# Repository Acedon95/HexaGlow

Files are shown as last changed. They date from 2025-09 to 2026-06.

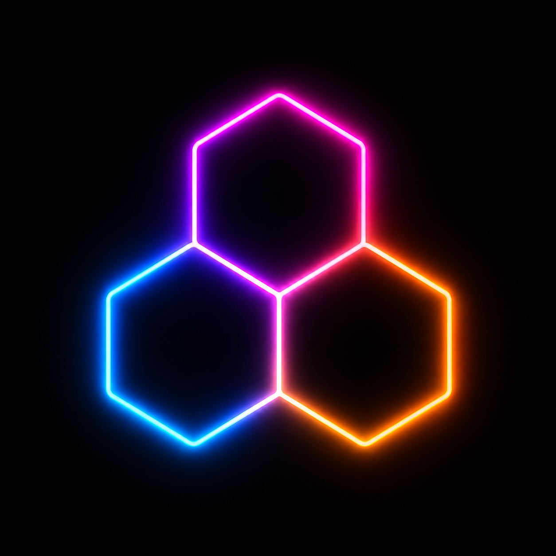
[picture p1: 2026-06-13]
app/hexaglow_app/assets/hexaglow_app_symbol.png

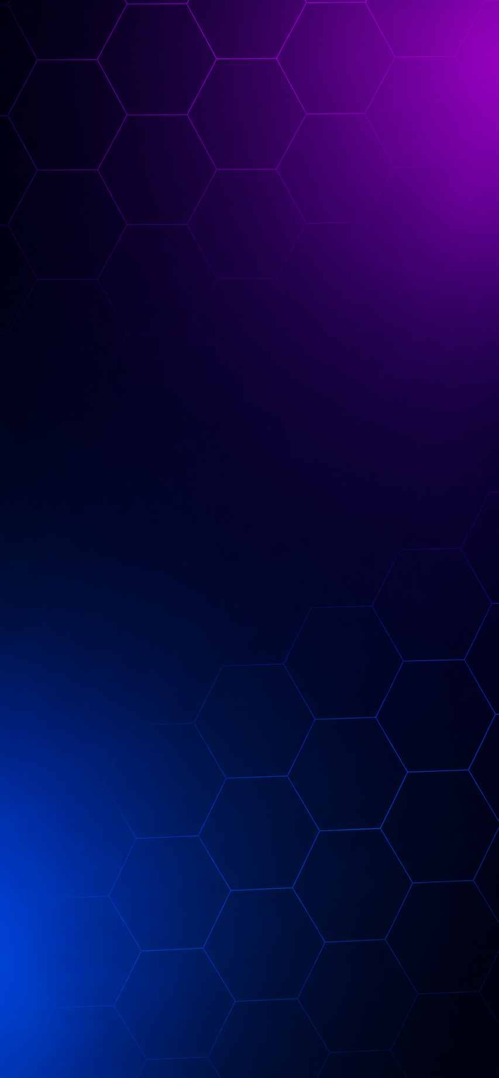
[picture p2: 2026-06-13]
app/hexaglow_app/assets/hexaglow_background_asset.png

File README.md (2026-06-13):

# HexaGlow

HexaGlow is a physical LED art piece made of **7 hexagons**, each ringed by
**18 WS2812B LEDs** (126 LEDs total), wired as one shared NeoPixel strip and
driven by an **ESP32**. The ESP32 connects to your WiFi and listens for
simple UDP text commands, which it translates into LED colors.

A companion **Flutter app** (Windows desktop + Android) provides a visual,
drag-to-arrange control surface: arrange the 7 hexagons to match your
physical layout, then tap edges/hexagons to pick colors, adjust brightness,
save/load presets, and clear the whole piece.

```
HexaGlow/
├── src/, include/, lib/, test/   ESP32 firmware (PlatformIO project)
├── data/                         SPIFFS filesystem image (WiFi credentials)
├── platformio.ini                Firmware build configuration
├── app/hexaglow_app/             Flutter app (Windows + Android)
└── hexagon_ring_outer100mm_*.stl 3D-printable hexagon ring (100mm, for 18 LEDs)
```

---

## 1. Firmware (ESP32)

The firmware is a [PlatformIO](https://platformio.org/) project rooted at
the repo root (`platformio.ini`, `src/`, `include/`).

### 1.1 Hardware setup

- **Board**: ESP32 dev kit (configured as `fm-devkit` in `platformio.ini`)
- **Data pin**: GPIO 4 (`LED_PIN` in [src/main.cpp](src/main.cpp))
- **LED count**: 126 (7 hexagons × 18 LEDs), type WS2812B (`NEO_GRB + NEO_KHZ800`)

NeoPixel best practices (see comments at the top of
[src/main.cpp](src/main.cpp)):
- Add a ~1000 µF capacitor across the strip's + and - rails.
- Keep the wire between the ESP32 and the first pixel short.
- Put a 300–500 Ω resistor on the data line.
- Always connect ground first when wiring live.
- A 3.3V → 5V logic-level converter on the data line is recommended.

### 1.2 WiFi configuration

The ESP32 connects to your WiFi as a client. Credentials are **not**
hardcoded — they're read at boot from a small config file stored in the
ESP32's SPIFFS filesystem.

1. Copy the example file and fill in your network details:
   ```
   data/.config.example  →  data/.config
   ```
   `data/.config` looks like:
   ```
   ssid:<your-ssid>
   password:<your-pw>
   ```
2. `data/.config` is **gitignored** (it contains real credentials) — make
   sure it exists locally before you upload the filesystem image.
3. Upload the filesystem image to the ESP32 (separately from the firmware):
   ```sh
   pio run --target uploadfs
   ```

You only need to redo step 3 when your WiFi credentials change.

### 1.3 Building and flashing the firmware

From the repo root (with the ESP32 connected via USB):

```sh
# Compile only (no hardware needed, useful to check for errors)
pio run

# Compile and flash to the connected ESP32
pio run --target upload

# Open a serial monitor at 115200 baud (boot logs, IP address, etc.)
pio device monitor
```

On boot, the ESP32:
1. Mounts SPIFFS and connects to WiFi using `data/.config`.
2. Prints its assigned IP address over serial (115200 baud) — **you need
   this IP address for the app's Settings screen**.
3. Plays a green "boot" animation, lighting up each hexagon in turn.
4. Starts listening for UDP commands on port **4210**.

> **Tip:** Your router may assign the ESP32 a different IP address after a
> power cycle unless you set up a DHCP reservation / static IP for it. If
> the app stops responding after a restart, check the serial monitor for the
> current IP and update it in the app's Settings screen.

### 1.4 UDP protocol reference

All commands are plain ASCII text, space-separated, sent as a single UDP
datagram to the ESP32's IP on port **4210**. This is the protocol the
Flutter app speaks; you can also test it manually with `nc -u <esp32-ip> 4210`.

| Command | Format | Description |
|---|---|---|
| Clear | `CLEAR` | Turns off all LEDs on all 7 hexagons. |
| Color all | `COLORALL r g b` | Sets every LED on the whole strip to one color. |
| Color hexagon | `COLORHEX hex_index r g b` | Sets every LED of one hexagon to one color. |
| Color edge | `COLOREDGE hex_index edge r g b` | Sets the 3 LEDs of one edge of one hexagon. |
| Color pixel | `COLORPIXEL hex_index index r g b` | Sets a single LED. |
| Brightness | `BRIGHTNESS value` | Sets global strip brightness (0-255). |

- `hex_index` is **1-7** (1-based, matches the numbers shown in the app).
- `edge` is **0-5** — one of the 6 edges of a hexagon (3 LEDs each).
- `index` (for `COLORPIXEL`) is the **absolute** LED index 0-125 across the
  whole strip.
- `r`, `g`, `b` are **0-255**.

---

## 2. Flutter App

Location: **`app/hexaglow_app/`**

A single Flutter codebase that builds for **Windows desktop** and
**Android**. It talks to the ESP32 over UDP using the protocol above.

### 2.1 What the app does

- **Home screen** — a freely-arrangeable canvas showing all 7 hexagons.
  - **Edit layout** (lock/unlock icon, top right): drag hexagons around to
    match your physical arrangement; the layout is saved automatically.
    While editing, each hexagon shows a rotate button that performs the
    **visual** 30° rotation of its on-screen graphic (purely cosmetic, to
    match how the hexagon is physically oriented).
  - **Color All**: opens a color wheel and sets every edge LED on every
    hexagon to the chosen color.
  - **Clear**: turns everything off (`CLEAR`).
  - **Brightness slider**: sets global strip brightness (sent once you
    release the slider).
- **Hexagon detail screen** (tap a hexagon): per-hexagon controls.
  - **Set whole hexagon color**: colors every LED of that hexagon.
  - **Edge list (Edge 0-5)**: tap an edge to pick its color individually.
  - **Rotate edges**: performs the **logical** 60° edge remap — use this if
    a hexagon's physical wiring is rotated relative to the others, so "Edge
    0" in the app always corresponds to the same physical edge across all
    hexagons, regardless of rotation.
  - **Individual pixels (advanced)**: a 3×6 grid for per-LED colors.
- **Color Presets screen** (palette icon): save the current full-piece
  color state (all hexagons + brightness) under a name, then reload or
  delete saved presets later.
- **Settings screen** (gear icon): set the ESP32's **IP address** and **UDP
  port** (default `192.168.1.100:4210`). This must match the IP printed by
  the ESP32 over serial (see [1.3](#13-building-and-flashing-the-firmware)).

All color/layout/preset/settings state is persisted locally on the device
(via `shared_preferences`). The LEDs themselves have no memory — if the
ESP32 reboots, it comes back to its boot animation and "off" state, and the
app's saved colors are just its best guess of what's currently showing until
you send a new command.

### 2.2 First-time setup

1. Flash and power on the ESP32 (see section 1) and note its IP address from
   the serial monitor.
2. Open the app → **Settings** → enter that IP address (and port `4210` if
   unchanged) → **Save**.
3. Go back to the home screen and try **Color All** or **Clear** to confirm
   the app and ESP32 can talk to each other.
4. Use **Edit layout** to drag the 7 hexagons into the same arrangement as
   your physical piece, and use the per-hexagon **Rotate edges** control if
   any hexagon's wiring is rotated relative to the others.

### 2.3 Where to find the app files

#### Windows

Build (debug or release) from `app/hexaglow_app/`:
```sh
flutter build windows --debug    # or --release
```
The executable is produced at:
```
app/hexaglow_app/build/windows/x64/runner/Debug/hexaglow_app.exe     (debug)
app/hexaglow_app/build/windows/x64/runner/Release/hexaglow_app.exe   (release)
```
Run it directly, or create a desktop/taskbar shortcut to it — the shortcut
will use HexaGlow's hexagon icon automatically.

#### Android

Build a release APK from `app/hexaglow_app/`:
```sh
flutter build apk --release
```
The APK is produced at:
```
app/hexaglow_app/build/app/outputs/flutter-apk/app-release.apk
```
Copy this file to your Android phone (USB, cloud storage, email, etc.) and
install it — you'll need to allow "install from unknown sources" since it's
not distributed via the Play Store.

### 2.4 Development

From `app/hexaglow_app/`:
```sh
flutter pub get      # install dependencies
flutter analyze       # static analysis
flutter test          # run unit tests (models, providers, UDP command formatting)
flutter run -d windows  # run with hot reload on Windows
```

App icons (Windows `.ico` + Android `mipmap-*`) and the app background are
generated/sourced from `app/hexaglow_app/assets/`:
- `hexaglow_app_symbol.png` — app icon (regenerate with
  `dart run flutter_launcher_icons` after replacing it)
- `hexaglow_background_asset.png` — app-wide background image

---

## 3. Misc

- `hexagon_ring_outer100mm_wall5mm_height10mm.stl` — 3D-printable ring that
  holds 18 LEDs per hexagon (100mm outer diameter, 5mm wall, 10mm height).
- `src/gui.py` — an older standalone Python/PyQt UDP test GUI, superseded by
  the Flutter app. Requires `PyQt6`; edit `ESP32_IP`/`ESP32_PORT` at the top
  before use.

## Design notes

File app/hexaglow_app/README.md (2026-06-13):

# HexaGlow App

Flutter control UI for the HexaGlow LED hexagon piece. Targets Windows
desktop and Android, communicating with the ESP32 over UDP on port 4210
using the same plain-text commands the firmware's `EventHandler` parses
(`COLORALL`, `COLORHEX`, `COLOREDGE`, `COLORPIXEL`, `BRIGHTNESS`, `CLEAR`).

## First-time setup

The `lib/`, `test/`, and `pubspec.yaml` in this directory were hand-written
before `flutter create` was run, so the platform folders (`android/`,
`windows/`, etc.) don't exist yet. Generate them in place:

1. Install the Flutter SDK and run `flutter doctor`. Make sure Windows
   desktop and Android toolchains show as ready (enable Windows desktop
   with `flutter config --enable-windows-desktop` if needed).
2. From this directory (`app/hexaglow_app`), run:

   ```
   flutter create --platforms=windows,android --org com.hexaglow .
   ```

   This adds the missing `android/`, `windows/`, and other scaffold files.
   It should not overwrite the existing `pubspec.yaml` or `lib/` since they
   already exist - afterwards run `git status`/`git diff` to confirm nothing
   unexpected changed (e.g. `pubspec.yaml`'s `name:` field should still read
   `hexaglow_app`).
3. Install dependencies:

   ```
   flutter pub get
   ```

4. Verify:

   ```
   flutter analyze
   flutter test
   ```

5. Run on Windows:

   ```
   flutter run -d windows
   ```

   Run on an Android device/emulator:

   ```
   flutter run -d <device-id>
   ```

   On Android, confirm `android/app/src/main/AndroidManifest.xml` contains
   `<uses-permission android:name="android.permission.INTERNET" />` (UDP
   sockets require it; `flutter create` includes it by default).

## Using the app

1. Open Settings (gear icon) and enter your ESP32's IP address (the port
   defaults to 4210, matching `Connection::localPort` in the firmware).
2. On the home screen, tap the lock icon to enter "Edit layout" mode and
   drag the 7 hexagons to mirror your physical arrangement. The layout is
   saved automatically.
3. Tap a hexagon (outside edit mode) to open its detail screen, where you
   can set its whole color or each of its 6 edges individually via a color
   wheel.
4. Use "Color All", the brightness slider, and "Clear" at the bottom of the
   home screen for global commands.

## Notes

- Edge numbering (0-5) is a UI convention matching the order
  `hexagonCorners()` produces in `lib/utils/hex_geometry.dart`; it doesn't
  necessarily correspond to a specific physical direction unless you verify
  it against your wiring.
- Colors shown in the UI are optimistic (last command sent from this app) -
  the firmware has no state read-back, so the UI resets to black on
  restart.
- The companion firmware change adding `COLORHEX hex_index r g b` lives in
  `src/EventHandler.cpp` at the repo root.

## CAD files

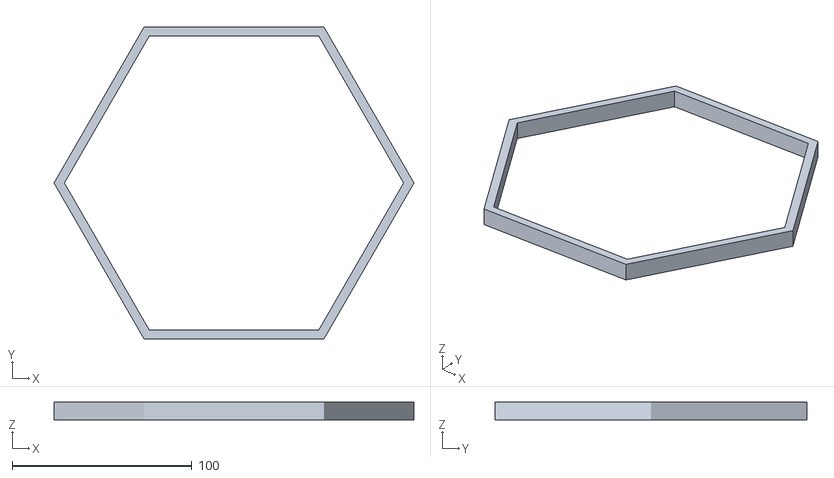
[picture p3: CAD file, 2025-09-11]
hexagon_ring_outer100mm_wall5mm_height10mm.stl
200.0 x 173.2 x 10.0

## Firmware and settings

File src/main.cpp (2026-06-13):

// "NEOPIXEL BEST PRACTICES for most reliable operation:
// - Add 1000 uF CAPACITOR between NeoPixel strip's + and - connections.
// - MINIMIZE WIRING LENGTH between microcontroller board and first pixel.
// - NeoPixel strip's DATA-IN *should* pass through a 300-500 OHM RESISTOR.
// - AVOID connecting NeoPixels on a LIVE CIRCUIT. If you must, ALWAYS
//   connect GROUND (-) first, then +, then data.
// - When using a 3.3V microcontroller with a 5V-powered NeoPixel strip,
//   a LOGIC-LEVEL CONVERTER on the data line is STRONGLY RECOMMENDED.
// (Skipping these may work OK on your workbench but can fail in the field)"
//
// Just use a WS2812b, an arduino and a compatible power supply.
// For led strips consuming <= 15W, you can solder the 5v wire of the usb cable directly
//  to the board and make use of power share (BIOS and Motherboard dependable)
// Costs: max.: 45€ for 5m

#include <Adafruit_NeoPixel.h>  // ignore this error in vscode. The Arduino IDE will compile it and upload it to the board.
#include <WiFi.h>
#include <iostream>
#include <ESP32Ping.h>
#include <WiFiUdp.h>
#include <string>
#include "connection.hpp"
#include "hexagon.hpp"
#include "EventHandler.hpp"
#include "Event.hpp"
#include <memory>
#include <SPIFFS.h>
#include <fstream>
#ifdef __AVR__
#include <avr/power.h>  // Required for 16 MHz Adafruit Trinket
#endif

// Which pin on the Arduino is connected to the strip?
#define LED_PIN 4

// How many LEDs are attached to the Arduino?
#define LED_COUNT 126

// Declare our NeoPixel strip object:
// Argument 1 = Number of pixels in NeoPixel strip
// Argument 2 = Arduino pin number (most are valid)
// Argument 3 = Pixel type flags, add together as needed:
Adafruit_NeoPixel strip(LED_COUNT, LED_PIN, NEO_GRB + NEO_KHZ800);

unsigned int localPort = 4210;  // Port für eingehende "Pings"

Connection conn; // will be initialized via move in setup
Hexagon hexagons[7];
EventHandler eventHandler; // will be initialized in setup


void boot(){
  // Function for led pattern on boot up, one hex after another lighting up green
  for(int i = 0; i < 7; i++){
    hexagons[i].set_all_pixels(0, 150, 0);
    strip.show();
    delay(200);
  }
}


// setup() function -- runs once at startup --------------------------------
void setup() {
  Serial.begin(115200);

  // Initialize SPIFFS
  if (!SPIFFS.begin(true)) {
      Serial.println("SPIFFS Mount Failed");
      return;
  }

  strip.begin();
  strip.fill(strip.Color(150, 150, 150), 0, LED_COUNT);
  strip.show();  // Update strip with new contents

  // Initialize objects in-place and move them to globals
  Connection tempConn(true, localPort);
  conn = std::move(tempConn);

  conn.create_listener();

  /* Here we go with two hexagons, each with 18 leds, sharing the same strip
    But I really want for the future a setup where we wait for the user to input the amount of hexagons
    and the amount of leds per hexagon via a configuration file or a simple web interface.
    And then create the hexagons dynamically via new Hexagon[hex_count]; and not via static array.
    This will also require changes in EventHandler and Event to be able to adress the hexagons dynamically.
  */
  eventHandler = EventHandler(hexagons, 9, &strip);

  Hexagon tempHex0(&strip, 1, 18, LED_COUNT);
  Hexagon tempHex1(&strip, 2, 18, LED_COUNT);
  Hexagon tempHex2(&strip, 3, 18, LED_COUNT);
  Hexagon tempHex3(&strip, 4, 18, LED_COUNT);
  Hexagon tempHex4(&strip, 5, 18, LED_COUNT);
  Hexagon tempHex5(&strip, 6, 18, LED_COUNT);
  Hexagon tempHex6(&strip, 7, 18, LED_COUNT);

  hexagons[0] = std::move(tempHex0);
  hexagons[1] = std::move(tempHex1);
  hexagons[2] = std::move(tempHex2);
  hexagons[3] = std::move(tempHex3);
  hexagons[4] = std::move(tempHex4);
  hexagons[5] = std::move(tempHex5);
  hexagons[6] = std::move(tempHex6);

  Serial.println("Setup complete.");
  Serial.print("IP address: ");
  Serial.println(conn.ipAddress);
  Serial.print("Listening on port ");
  Serial.println(localPort);
  boot();
  //strip.show();
}

// loop() function -- runs repeatedly as long as board is on ---------------
void loop() {
  String packet = conn.listen_for_packets();
  if (packet.length() > 0) {
    Event event = eventHandler.create_event_from_string(std::string(packet.c_str()));
    eventHandler.process_event(event);
    //strip.show();
  }
}

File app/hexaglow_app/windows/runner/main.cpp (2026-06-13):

#include <flutter/dart_project.h>
#include <flutter/flutter_view_controller.h>
#include <windows.h>

#include "flutter_window.h"
#include "utils.h"

int APIENTRY wWinMain(_In_ HINSTANCE instance, _In_opt_ HINSTANCE prev,
                      _In_ wchar_t *command_line, _In_ int show_command) {
  // Attach to console when present (e.g., 'flutter run') or create a
  // new console when running with a debugger.
  if (!::AttachConsole(ATTACH_PARENT_PROCESS) && ::IsDebuggerPresent()) {
    CreateAndAttachConsole();
  }

  // Initialize COM, so that it is available for use in the library and/or
  // plugins.
  ::CoInitializeEx(nullptr, COINIT_APARTMENTTHREADED);

  flutter::DartProject project(L"data");

  std::vector<std::string> command_line_arguments =
      GetCommandLineArguments();

  project.set_dart_entrypoint_arguments(std::move(command_line_arguments));

  FlutterWindow window(project);
  Win32Window::Point origin(10, 10);
  Win32Window::Size size(1280, 720);
  if (!window.Create(L"hexaglow_app", origin, size)) {
    return EXIT_FAILURE;
  }
  window.SetQuitOnClose(true);

  ::MSG msg;
  while (::GetMessage(&msg, nullptr, 0, 0)) {
    ::TranslateMessage(&msg);
    ::DispatchMessage(&msg);
  }

  ::CoUninitialize();
  return EXIT_SUCCESS;
}

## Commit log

2025-09-11 feat: stl file for big hexagon
    [hexagon_ring_outer100mm_wall5mm_height10mm.stl]
2025-09-17 fix: share strip object between hexagons to avoid clearing strip buffer
    [main.cpp]
2026-06-13 fix: edge remapping, performance fix, app icons
    [connection.cpp, main.cpp]
